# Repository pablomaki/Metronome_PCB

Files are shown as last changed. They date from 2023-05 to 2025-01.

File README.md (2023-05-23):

# Metronome_PCB

| ❗ NOTE          |
|:---------------------------|
| This design is still work in process. PCB has been confirmed to work on breadboard, but actual PCB is still in mail. After the PCB has been confirmed to be functioning properly, I will add BOM and design an enclosure for it. |

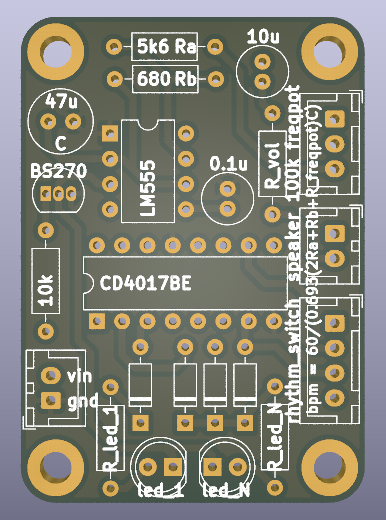
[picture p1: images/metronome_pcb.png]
KiCAD PCB render.


## Description

This metronome PCB is based on a simple 555 oscillator producing frequency adjustable square wave with 0.5 dutycycle. In addition the board contains CD4017BE counter circuit that can be used to drive two separate LEDs so that one flashes either every 2, 3 or 4 beats while the other flashes on every beat. The length of a bar can be chosen by separate switch or just hardwired for specific one.

The metronome works with supply voltage of 5 to 15 V, 9V battery is recommended and works well for this purpose. Note that the voltage used may affect the loudness of the speaker. Loudness can also be affected by a separate volume resistor.

## BOM

TO BE ADDED

## Enclosure

TO BE ADDED

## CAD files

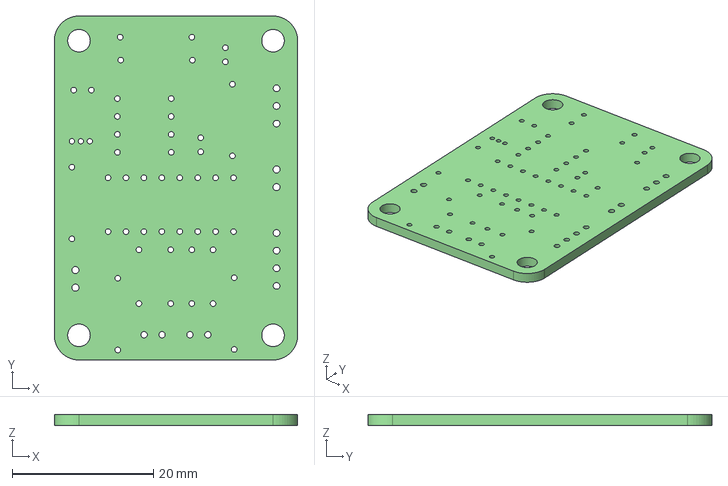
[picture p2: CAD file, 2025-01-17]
kicad/metronome.step
34.5 x 48.8 x 1.60 mm

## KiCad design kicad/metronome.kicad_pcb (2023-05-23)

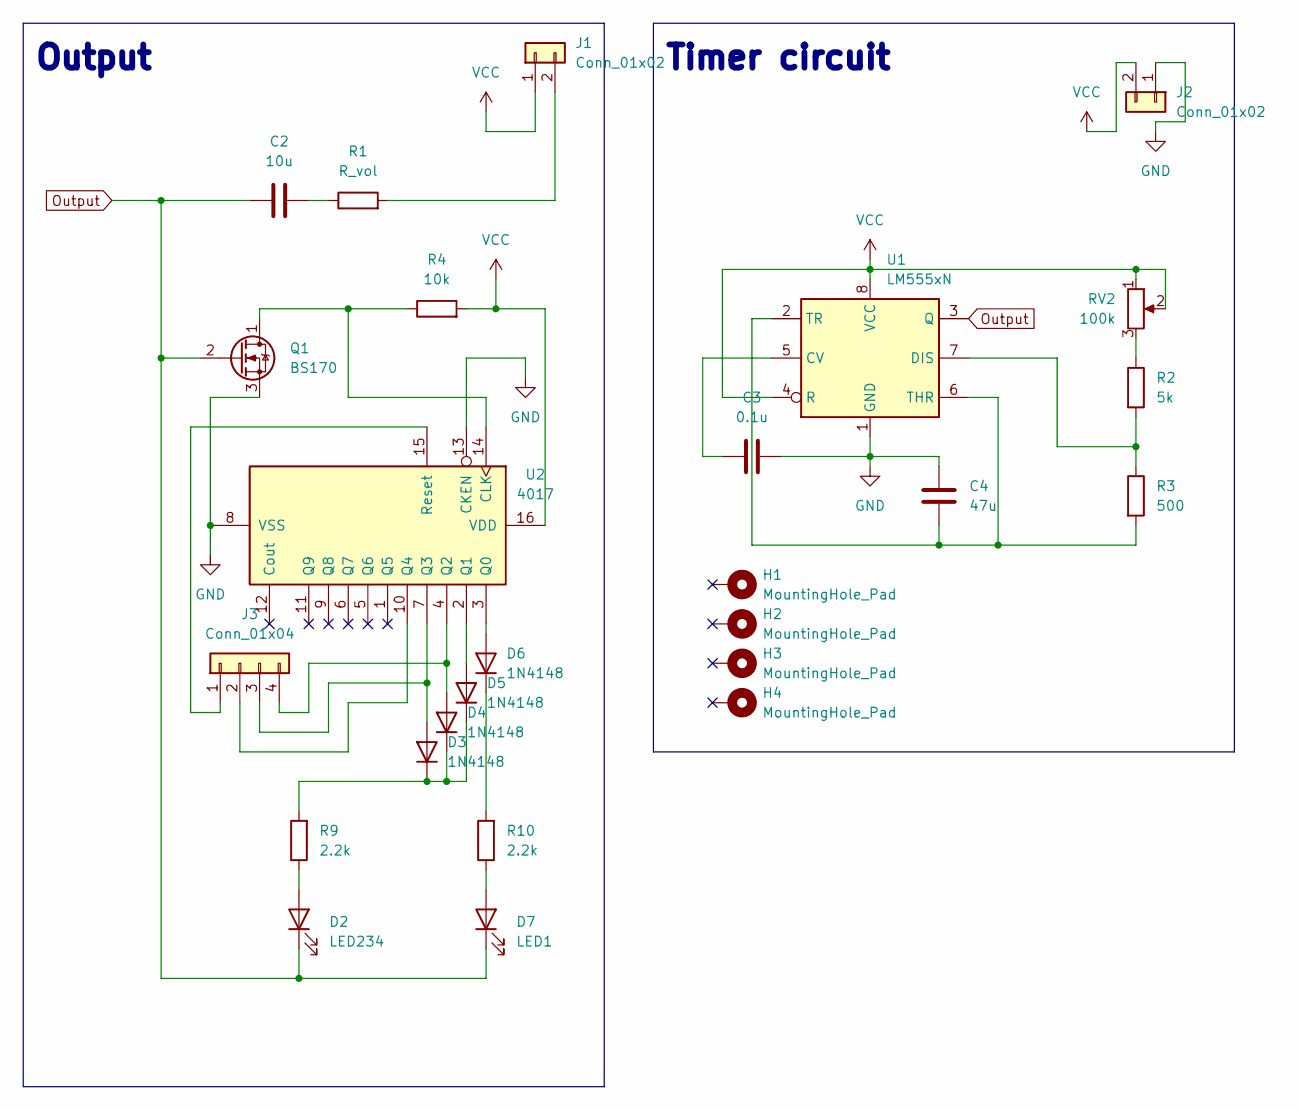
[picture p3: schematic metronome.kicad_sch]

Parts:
C2: 10u; C_Radial_D5.0mm_H11.0mm_P2.00mm
C3: 0.1u; C_Radial_D5.0mm_H11.0mm_P2.00mm
C4: 47u; C_Radial_D6.3mm_H11.0mm_P2.50mm
D2: LED234; LED_D5.0mm
D3, D4, D5, D6: 1N4148; D_DO-35_SOD27_P7.62mm_Horizontal
D7: LED1; LED_D5.0mm
H1, H2, H3, H4: MountingHole_Pad; MountingHole_3.2mm_M3_ISO7380_Pad
J1, J2: Conn_01x02; JST_XH_B2B-XH-A_1x02_P2.50mm_Vertical
J3: Conn_01x04; JST_XH_B4B-XH-A_1x04_P2.50mm_Vertical
Q1: BS170; TO-92_Inline
R1: R_vol; R_Axial_DIN0207_L6.3mm_D2.5mm_P10.16mm_Horizontal
R2: 5k; R_Axial_DIN0207_L6.3mm_D2.5mm_P10.16mm_Horizontal
R3: 500; R_Axial_DIN0207_L6.3mm_D2.5mm_P10.16mm_Horizontal
R4: 10k; R_Axial_DIN0207_L6.3mm_D2.5mm_P10.16mm_Horizontal
R9, R10: 2.2k; R_Axial_DIN0207_L6.3mm_D2.5mm_P10.16mm_Horizontal
RV2: 100k; JST_XH_B3B-XH-A_1x03_P2.50mm_Vertical
U1: LM555xN; DIP-8_W7.62mm
U2: 4017; DIP-16_W7.62mm

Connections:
GND: C3.1, C4.1, J2.1, Q1.3 (S), U1.1 (GND), U2.8 (VSS), U2.13 (CKEN)
unnamed: C2.2, R1.1
unnamed: C3.2, U1.5 (CV)
unnamed: C4.2, R3.2, U1.2 (TR), U1.6 (THR)
unnamed: D2.2 (A), R9.1
unnamed: D3.1 (K), D4.1 (K), D5.1 (K), R9.2
unnamed: D3.2 (A), J3.3, U2.7 (Q3)
unnamed: D4.2 (A), J3.4, U2.4 (Q2)
unnamed: D5.2 (A), U2.2 (Q1)
unnamed: D6.1 (K), R10.2
unnamed: D6.2 (A), U2.3 (Q0)
unnamed: D7.2 (A), R10.1
unnamed: J1.2, R1.2
unnamed: Q1.1 (D), R4.1, U2.14 (CLK)
unnamed: R2.1, RV2.3
unnamed: R2.2, R3.1, U1.7 (DIS)
unnamed: J3.2, U2.10 (Q4)
unnamed: J3.1, U2.15 (Reset)
Output: C2.1, D2.1 (K), D7.1 (K), Q1.2 (G), U1.3 (Q)
VCC: J1.1, J2.2, R4.2, RV2.1, RV2.2, U1.4 (R), U1.8 (VCC), U2.16 (VDD)

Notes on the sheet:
Output
Timer circuit

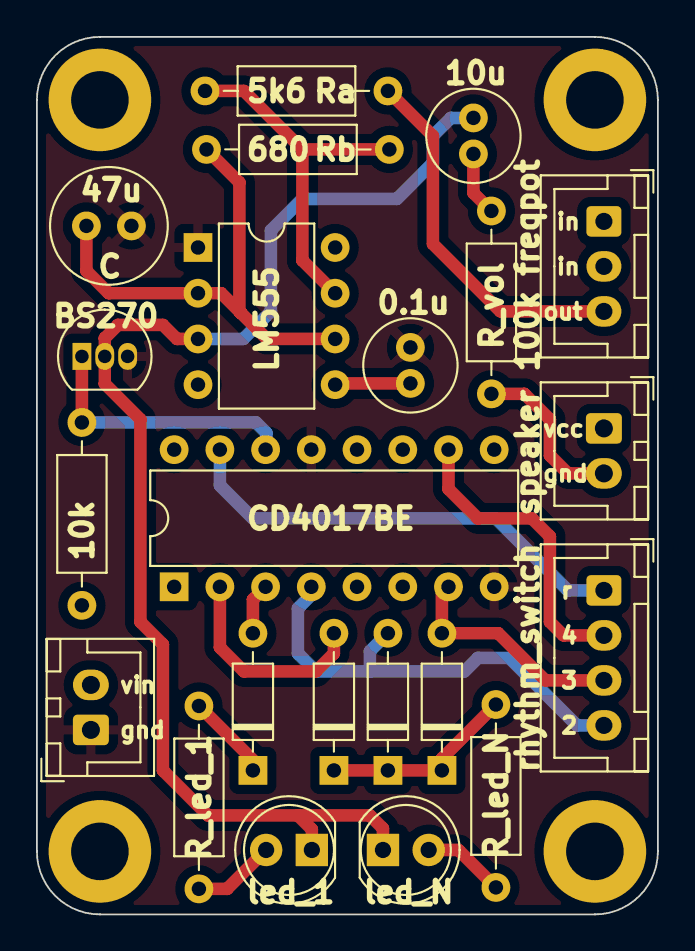
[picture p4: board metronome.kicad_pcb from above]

Board: 2 copper layers, 34.5 x 48.8 mm, 26 parts (0 on the bottom side), 20 nets.

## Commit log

2023-05-18 Initial push
    [metronome-B_Cu.gbr, metronome-B_Mask.gbr, metronome-B_Paste.gbr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]
2023-05-23 Update gerber files
    [metronome-B_Cu.gbr, metronome-B_Mask.gbr, metronome-B_Paste.gbr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]
2025-01-17 Add PCB .step file
    [metronome.step]
